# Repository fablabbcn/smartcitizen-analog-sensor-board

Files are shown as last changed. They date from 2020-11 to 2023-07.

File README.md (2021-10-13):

# SmartCitizen Analog Sensor Boards

This repository contains a set of boards that can interface the Smart Citizen Kit in different ways.

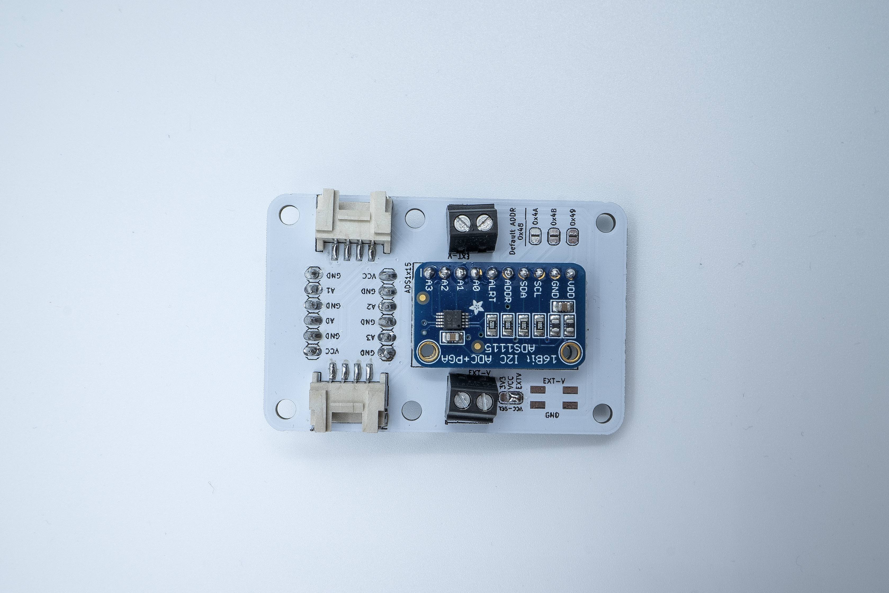
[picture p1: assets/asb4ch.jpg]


The SmartCitizen ASB is an expansion board for the [Smart Citizen Kit](https://github.com/fablabbcn/smartcitizen-kit-21) that provides connectivity to analog sensors with a high precission ADS1115 via I2C, with four configurable addresses. Daisy chainable up to 4 boards (or 2 in 8ch version) - with a total of 16 analog channels.

|Variant|# of Channels|External AREF needed|ADS format|
|:-:|:-:|:-:|:-:|
|4-channel|4|Y|SMD or [shield by adafruit](https://www.adafruit.com/product/1085)|
|8-channel-step|8|N|SMD|

## Characteristics

### Operating voltage

Natively operates at 3.3V, but can use also up to 5.5V in EXT-V, and with a selectable jumper. It integrates a level-shifter from the GROVE connector's voltage to EXT-V.

### Connectivity

I2C, from 3.3V up to 5.5V.

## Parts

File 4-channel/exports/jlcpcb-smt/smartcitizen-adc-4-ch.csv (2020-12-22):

Comment | Designator | Footprint | LCSC
10n | C1 | fab:fab-C1206FAB | C1944
100n | C2 | fab:fab-C1206FAB | C24497
1uF | C3,C4 | fab:fab-C1206FAB | C1848
1.5 kΩ | FB1,FB2 | fab:fab-R1206FAB | C21517
10k | R1,R2,R3,R4,R5,R6 | fab-R1206FAB | C17902
NMOSFET | T1,T2 | fab-SOT-23 | C431497
ADS1115IDGS | U1 | Package_SO:TSSOP-10_3x3mm_P0.5mm | C37593

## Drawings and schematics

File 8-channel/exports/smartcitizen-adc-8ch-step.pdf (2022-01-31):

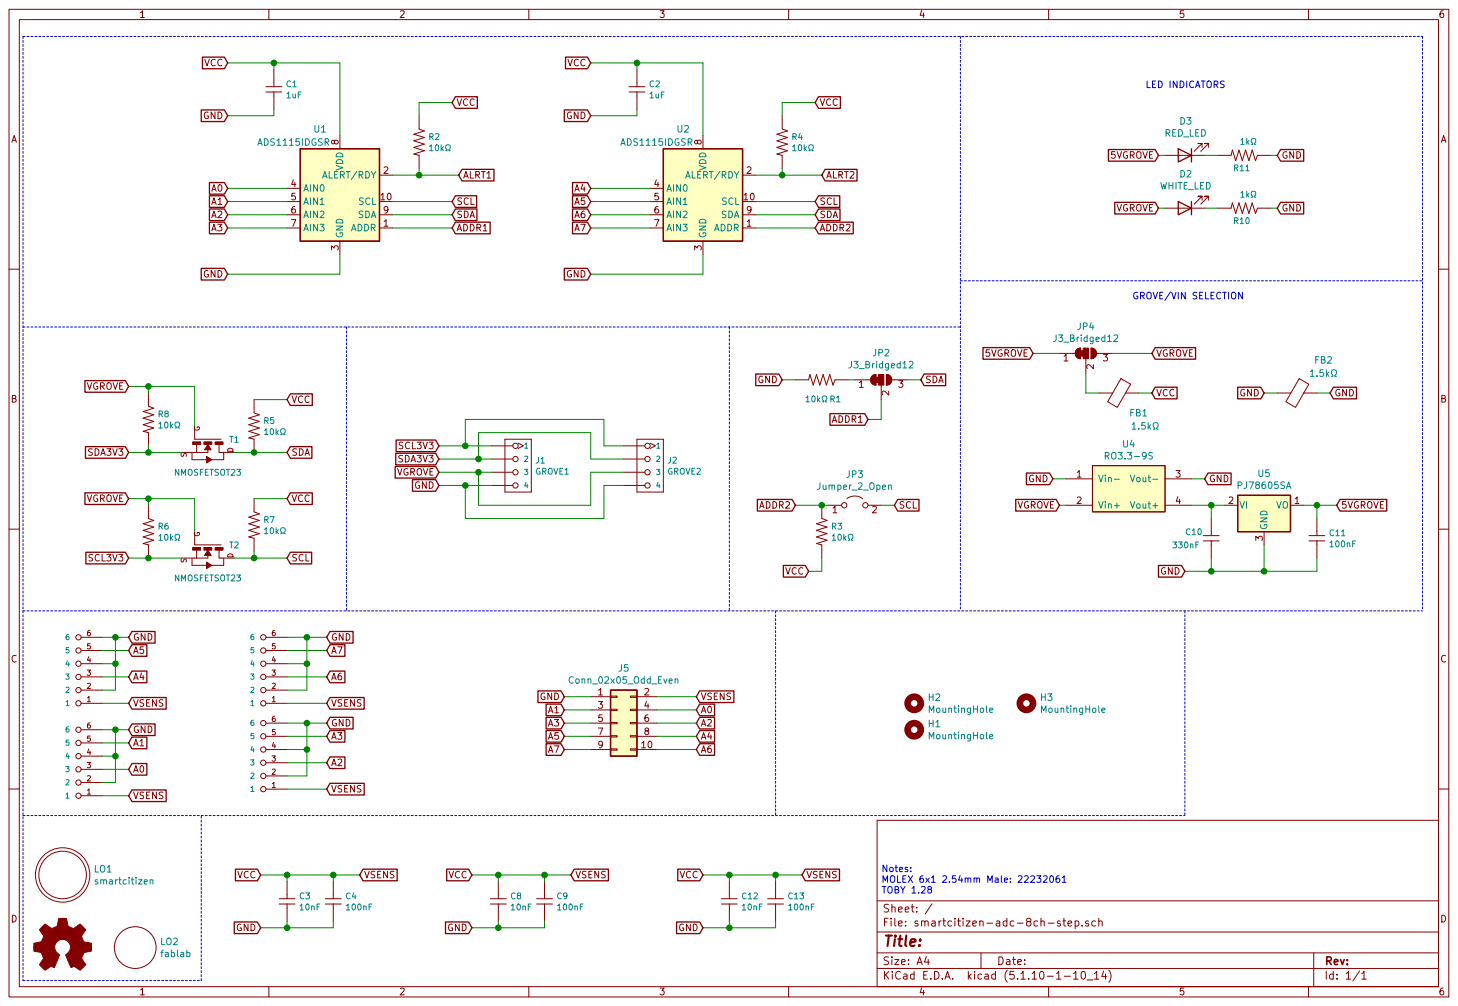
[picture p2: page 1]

Notes: MOLEX 6x1 2.54mm Male: 22232061 TOBY 1.28

File: smartcitizen-adc-8ch-step.sch Sheet: /
Id: 1/1 Title:

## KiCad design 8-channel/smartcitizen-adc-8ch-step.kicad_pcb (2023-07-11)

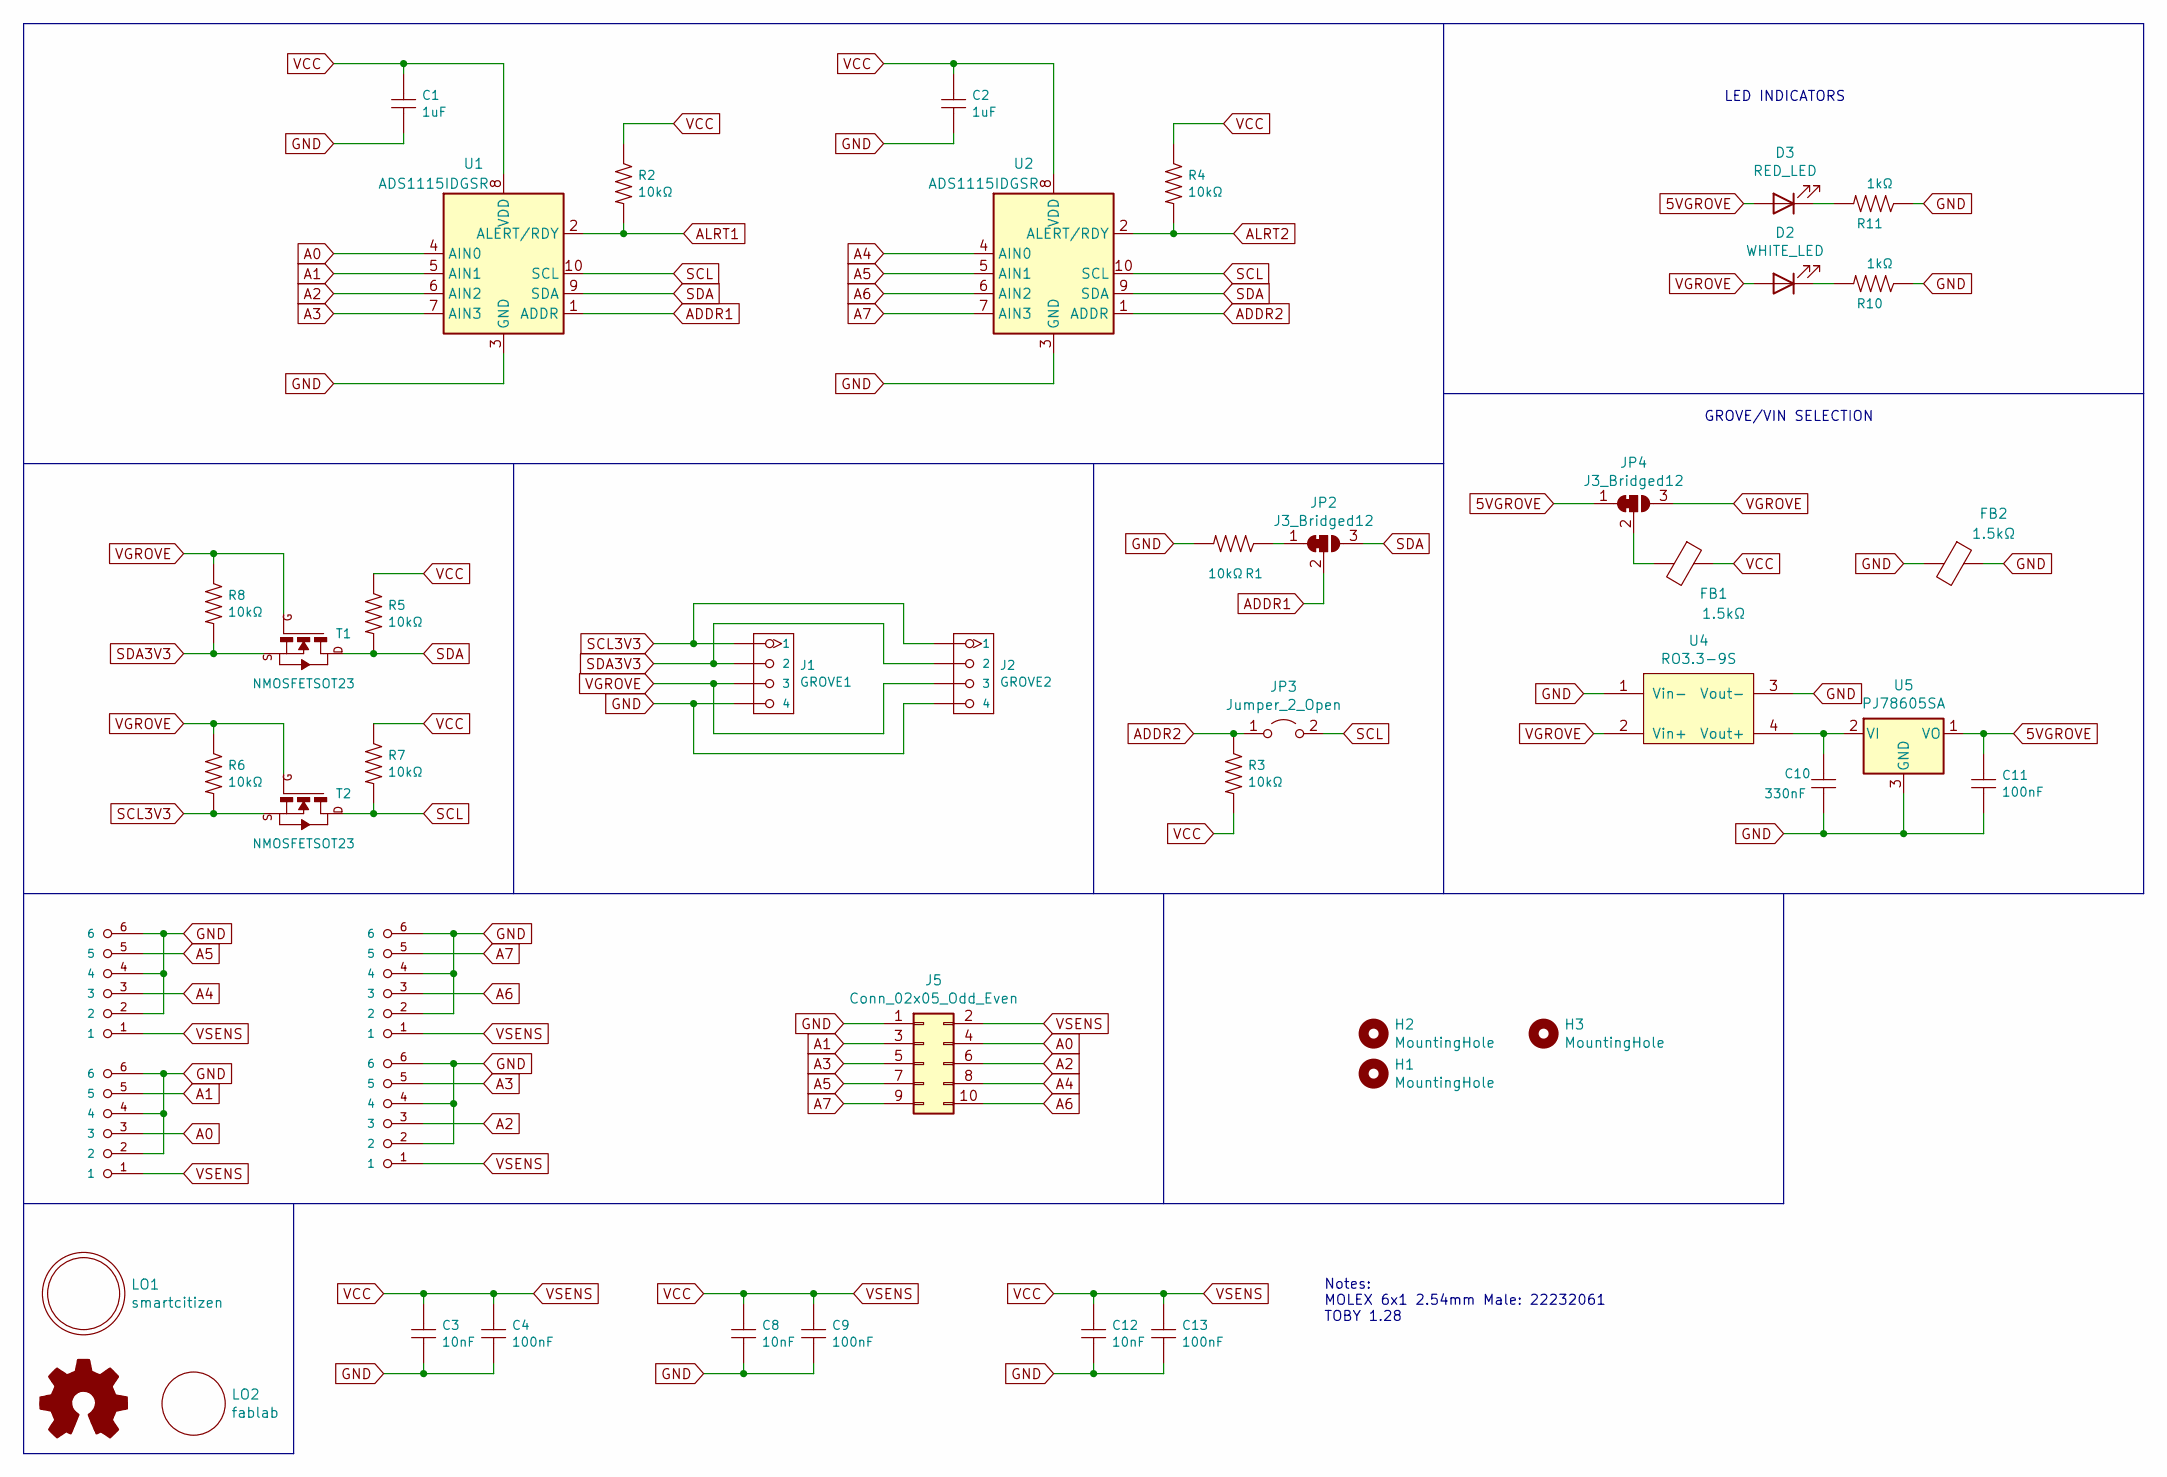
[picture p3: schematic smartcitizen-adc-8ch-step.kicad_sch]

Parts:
C1, C2: 1uF; C_0805_2012Metric; MFR.Part # CL21B105KBFNNNE; LCSC C28323
C3, C8, C12: 10nF; C_0805_2012Metric_Pad1.18x1.45mm_HandSolder; MFR.Part # CC0805KRX7R0BB103; LCSC C107135
C4, C9, C13: 100nF; C_0805_2012Metric_Pad1.18x1.45mm_HandSolder; MFR.Part # CC0805JRX7R9BB104; LCSC C111492
C10: 330nF; fab-C1206FAB; MFR.Part # CL31B334KBFNNNE; LCSC C307572
C11: 100nF; fab-C1206FAB; MFR.Part # CL31B104KBCNNNC; LCSC C24497
D2: WHITE_LED; LED_0402_1005Metric; MFR.Part # BL-HZ337A-L6-TRB; LCSC C189305
D3: RED_LED; LED_0402_1005Metric; MFR.Part # 2SA0402S11A0JT01; LCSC C233194
FB1, FB2: 1.5kΩ; R_0805_2012Metric_Pad1.20x1.40mm_HandSolder; MFR.Part # MMZ2012Y152B; LCSC C21517
H1, H2, H3: MountingHole; MountingHole_3.2mm_M3
J1: GROVE1; HW4-SMD-2.0-90D
J2: GROVE2; HW4-SMD-2.0-90D
J5: Conn_02x05_Odd_Even; PinSocket_2x05_P2.00mm_Vertical
JP2, JP4: J3_Bridged12; SolderJumper-3_P1.3mm_Bridged12_RoundedPad1.0x1.5mm
JP3: Jumper_2_Open; SolderJumper-2_P1.3mm_Open_RoundedPad1.0x1.5mm
LO1: smartcitizen
LO2: fablab
M1, M2, M3, M4: PINHD-1x06-HEADER; Molex_KK-254_AE-6410-06A_1x06_P2.54mm_Vertical
OSH1: Logo_Open_Hardware_Small; OSHW-Symbol_6.7x6mm_SilkScreen
R1, R2, R3, R4, R5, R6, R7, R8: 10kΩ; R_0603_1608Metric; MFR.Part # 0603WAF1002T5E; LCSC C25804
R10, R11: 1kΩ; R_0402_1005Metric; MFR.Part # 0402WGF1001TCE; LCSC C11702
T1, T2: NMOSFETSOT23; fab-SOT-23; MFR.Part # SI2310; LCSC C431497
U1, U2: ADS1115IDGSR; TSSOP-10_3x3mm_P0.5mm; MFR.Part # ADS1115IDGSR; LCSC C37593
U4: RO3.3-9S; Converter_DCDC_RECOM_RO_3.309S
U5: PJ78605SA; SOT-23; LCSC C411751

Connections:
5VGROVE: C11.1, D3.2 (A), JP4.1 (A), U5.1 (VO)
A0: J5.4, M2.3, U1.4 (AIN0)
A1: J5.3, M2.5, U1.5 (AIN1)
A2: J5.6, M4.3, U1.6 (AIN2)
A3: J5.5, M4.5, U1.7 (AIN3)
A4: J5.8, M1.3, U2.4 (AIN0)
A5: J5.7, M1.5, U2.5 (AIN1)
A6: J5.10, M3.3, U2.6 (AIN2)
A7: J5.9, M3.5, U2.7 (AIN3)
ADDR1: JP2.2 (C), U1.1 (ADDR)
ADDR2: JP3.1 (A), R3.1, U2.1 (ADDR)
ALRT1: R2.2, U1.2 (ALERT/RDY)
ALRT2: R4.2, U2.2 (ALERT/RDY)
GND: C1.2, C2.2, C3.2, C4.2, C8.2, C9.2, C10.2, C11.2, C12.2, C13.2, FB2.1, FB2.2, J1.4, J2.4, J5.1, M1.2, M1.4, M1.6, M2.2, M2.4, M2.6, M3.2, M3.4, M3.6, M4.2, M4.4, M4.6, R1.2, R10.1, R11.1, U1.3 (GND), U2.3 (GND), U4.1 (Vin-), U4.3 (Vout-), U5.3 (GND)
unnamed: C10.1, U4.4 (Vout+), U5.2 (VI)
unnamed: D2.1 (K), R10.2
unnamed: D3.1 (K), R11.2
unnamed: FB1.2, JP4.2 (C)
unnamed: JP2.1 (A), R1.1
SCL: JP3.2 (B), R7.2, T2.1 (D), U1.10 (SCL), U2.10 (SCL)
SCL3V3: J1.1, J2.1, R6.2, T2.2 (S)
SDA: JP2.3 (B), R5.2, T1.1 (D), U1.9 (SDA), U2.9 (SDA)
SDA3V3: J1.2, J2.2, R8.2, T1.2 (S)
VCC: C1.1, C2.1, C3.1, C4.1, C8.1, C9.1, C12.1, C13.1, FB1.1, J5.2, M1.1, M2.1, M3.1, M4.1, R2.1, R3.2, R4.1, R5.1, R7.1, U1.8 (VDD), U2.8 (VDD)
VGROVE: D2.2 (A), J1.3, J2.3, JP4.3 (B), R6.1, R8.1, T1.3 (G), T2.3 (G), U4.2 (Vin+)

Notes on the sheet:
LED INDICATORS
Notes: MOLEX 6x1 2.54mm Male: 22232061 TOBY 1.28
GROVE/VIN SELECTION

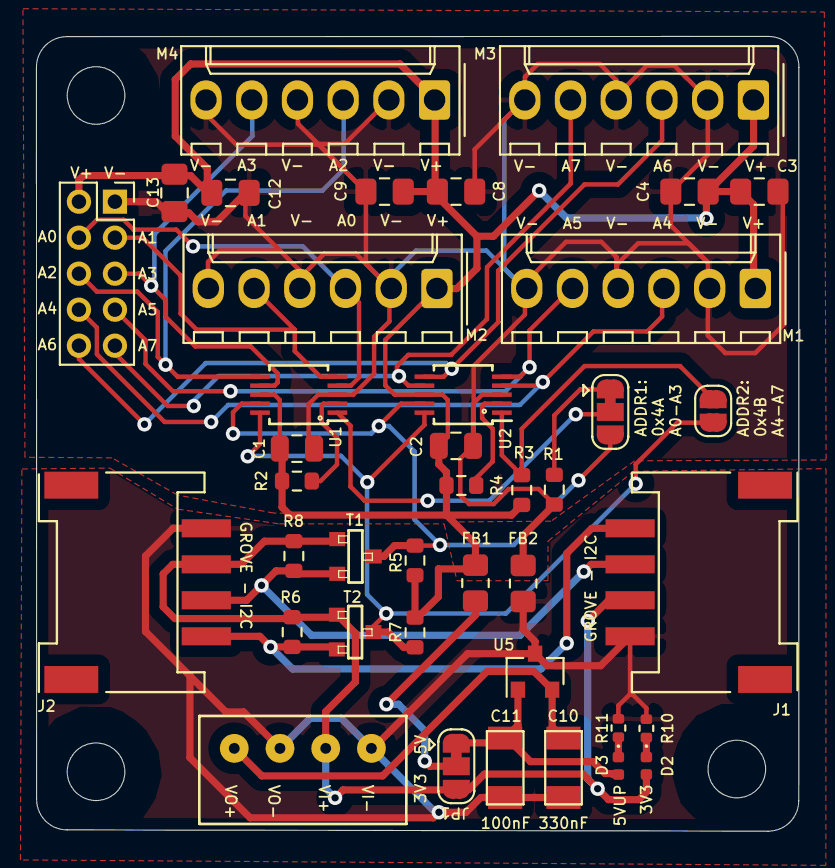
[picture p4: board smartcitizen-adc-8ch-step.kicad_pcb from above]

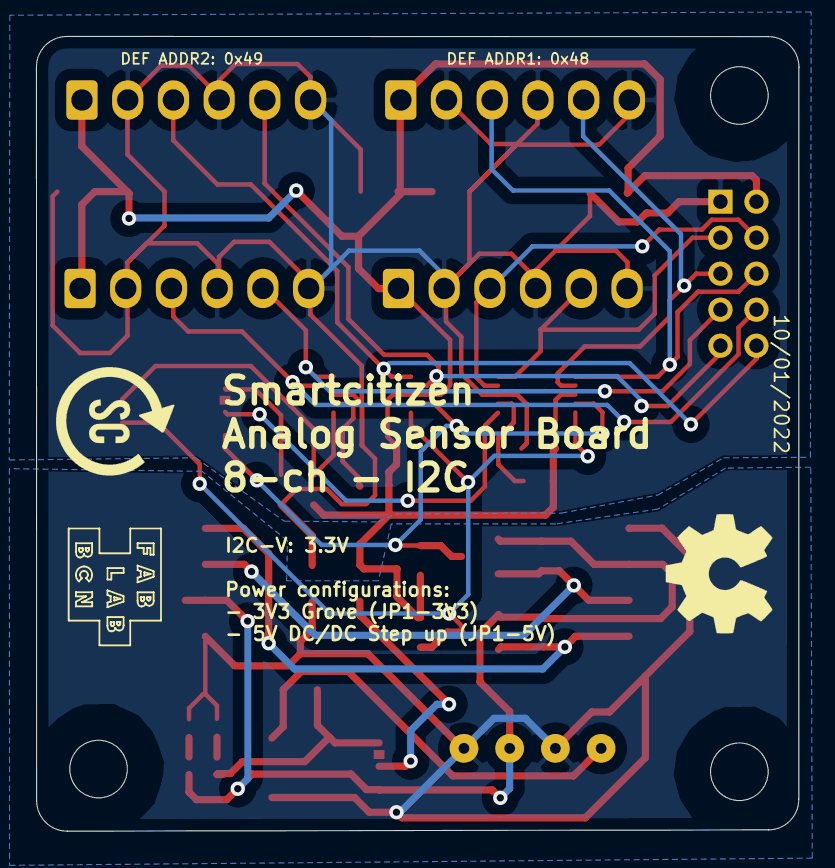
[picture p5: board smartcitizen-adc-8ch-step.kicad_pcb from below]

Board: 2 copper layers, 42.4 x 44.1 mm, 46 parts (3 on the bottom side), 25 nets.

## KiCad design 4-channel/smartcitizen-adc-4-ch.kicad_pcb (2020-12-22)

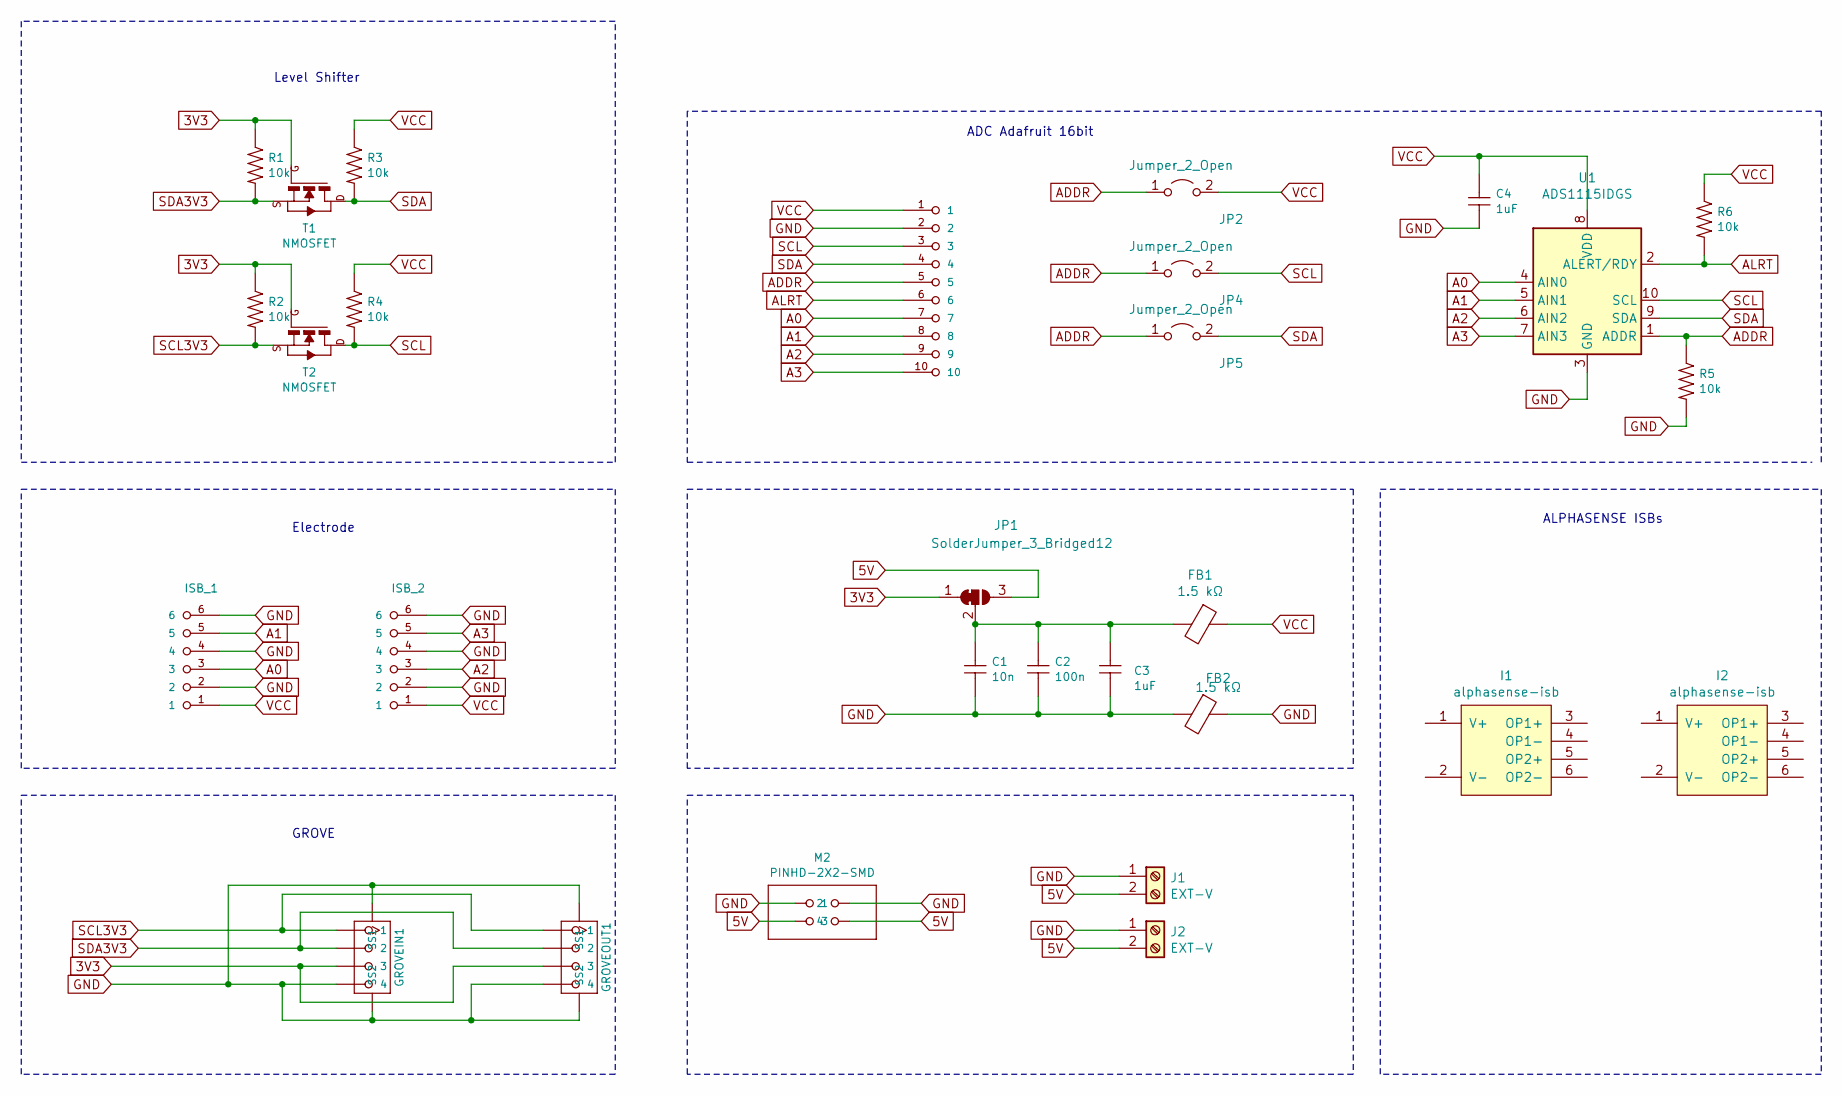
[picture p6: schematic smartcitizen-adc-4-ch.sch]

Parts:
C1: 10n; fab-C1206FAB; LCSC C1944
C2: 100n; fab-C1206FAB; LCSC C24497
C3, C4: 1uF; fab-C1206FAB; LCSC C1848
FB1, FB2: 1.5 kΩ; fab-R1206FAB; LCSC C21517
GROVEIN1: GROVE-CONNECTOR-SMD-90D_4+2P-2.0_; HW4-SMD-2.0-90D
GROVEOUT1: GROVE-CONNECTOR-DIP_4P-2.0_; HW4-SMD-2.0-90D
I1, I2: alphasense-isb
ISB_1, ISB_2: PINHD-1x06-HEADER; fab-1X06
J1, J2: EXT-V; TerminalBlock_Phoenix_PT-1,5-2-3.5-H_1x02_P3.50mm_Horizontal
JP1: SolderJumper_3_Bridged12; SolderJumper-3_P1.3mm_Bridged12_RoundedPad1.0x1.5mm_NumberL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
JP2, JP4, JP5: Jumper_2_Open; SolderJumper-2_P1.3mm_Open_RoundedPad1.0x1.5mm
M1: PINHD-1x10-HEADER; ads11x5
M2: PINHD-2X2-SMD; fab-2X02SMD
R1, R2, R3, R4, R5, R6: 10k; fab-R1206FAB; LCSC C17902
T1: NMOSFET; fab-SOT-23; LCSC C431497
T2: NMOSFET; fab-SOT-23; LCSC NCE2304
U1: ADS1115IDGS; TSSOP-10_3x3mm_P0.5mm; LCSC C37593

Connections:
3V3: GROVEIN1.3, GROVEOUT1.3, JP1.1 (A), R1.1, R2.1, T1.3 (G), T2.3 (G)
5V: J1.2, J2.2, JP1.3 (B), M2.3, M2.4
A0: ISB_1.3, M1.7, U1.4 (AIN0)
A1: ISB_1.5, M1.8, U1.5 (AIN1)
A2: ISB_2.3, M1.9, U1.6 (AIN2)
A3: ISB_2.5, M1.10, U1.7 (AIN3)
ADDR: JP2.1 (A), JP4.1 (A), JP5.1 (A), M1.5, R5.1, U1.1 (ADDR)
ALRT: M1.6, R6.2, U1.2 (ALERT/RDY)
GND: C1.2, C2.2, C3.2, C4.2, FB2.1, FB2.2, GROVEIN1.4, GROVEIN1.5 (SS1), GROVEIN1.6 (SS2), GROVEOUT1.4, GROVEOUT1.5 (SS1), GROVEOUT1.6 (SS2), ISB_1.2, ISB_1.4, ISB_1.6, ISB_2.2, ISB_2.4, ISB_2.6, J1.1, J2.1, M1.2, M2.1, M2.2, R5.2, U1.3 (GND)
unnamed: C1.1, C2.1, C3.1, FB1.2, JP1.2 (C)
SCL: JP4.2 (B), M1.3, R4.2, T2.1 (D), U1.10 (SCL)
SCL3V3: GROVEIN1.1, GROVEOUT1.1, R2.2, T2.2 (S)
SDA: JP5.2 (B), M1.4, R3.2, T1.1 (D), U1.9 (SDA)
SDA3V3: GROVEIN1.2, GROVEOUT1.2, R1.2, T1.2 (S)
VCC: C4.1, FB1.1, ISB_1.1, ISB_2.1, JP2.2 (B), M1.1, R3.1, R4.1, R6.1, U1.8 (VDD)

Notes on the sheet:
Level Shifter
ADC Adafruit 16bit
Electrode
GROVE
ALPHASENSE ISBs

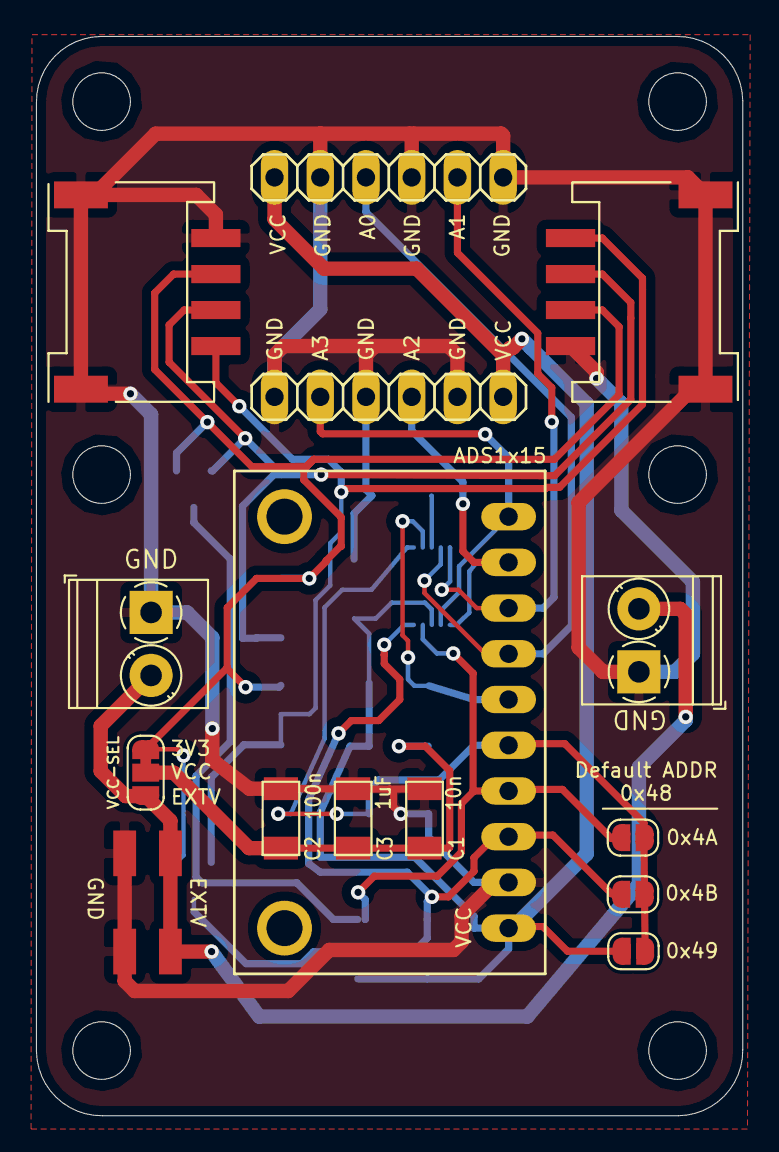
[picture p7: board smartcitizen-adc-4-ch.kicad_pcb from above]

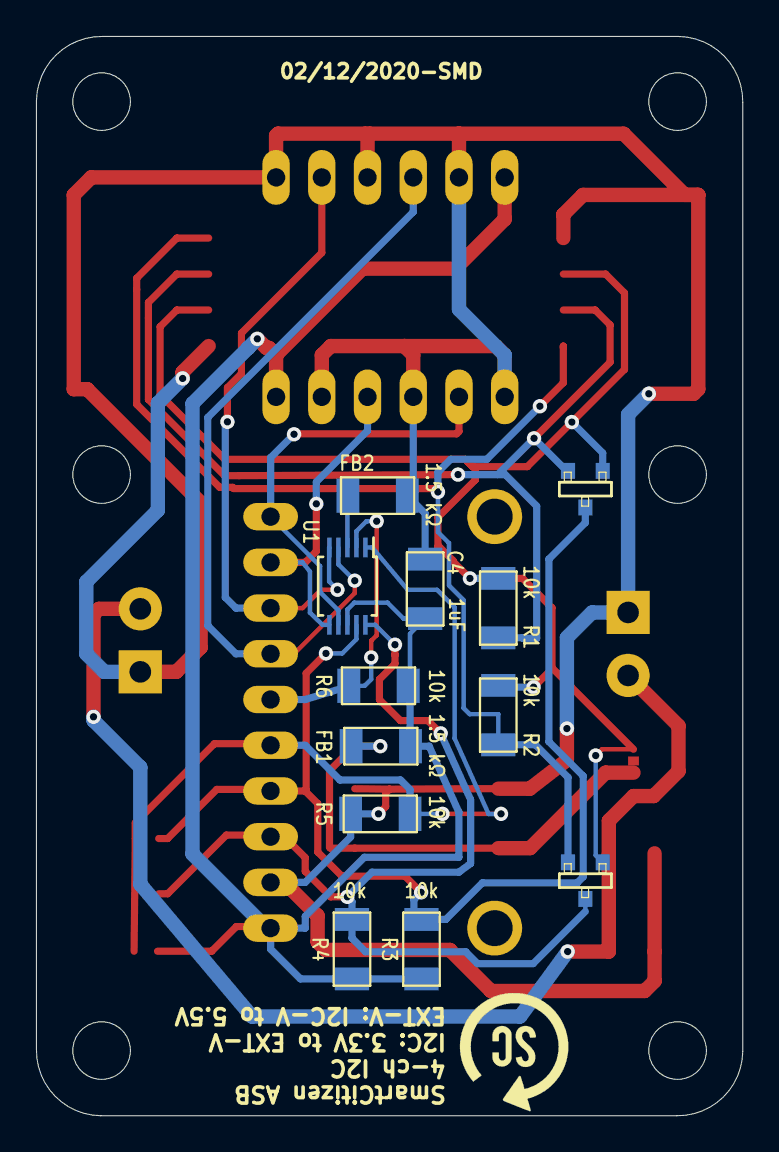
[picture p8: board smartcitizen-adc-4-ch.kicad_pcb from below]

Board: 2 copper layers, 39.2 x 60.0 mm, 27 parts (12 on the bottom side), 15 nets.

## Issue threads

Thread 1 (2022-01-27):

.SCH files will not open in Autodesk Eagle or Fusion 360

bryn51, 2022-01-27:
If I need to eyeball the schematic then I need a viewer that opens the files.  I am just guessing what to use; but most likely Eagle.

I find that there is no PDF version of the schematic available to view; and that the (.sch) files will not open in Autodesk Eagle (current version)  or Autodesk 360 (current version).

These issues are easily corrected; and should be.

oscgonfer, 2022-01-31:
The design files are done in Kicad 5, not supporting Autodesk stuff, sorry.

For the schematic, will add it now.

oscgonfer, 2022-01-31:
https://github.com/fablabbcn/smartcitizen-analog-sensor-board/blob/master/8-channel/exports/smartcitizen-adc-8ch-step.pdf

Closed 2022-01-31.

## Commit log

2020-06-30 4 channel ADC board
    [smartcitizen-adc-4-ch.csv, smartcitizen-adc-4-ch.kicad_pcb, smartcitizen-adc-4-ch.sch]
2020-07-01 Add 8 channel board
    [smartcitizen-adc-8ch.csv, smartcitizen-adc-8ch.kicad_pcb, smartcitizen-adc-8ch.sch]
2020-07-06 Add gerbers
    [smartcitizen-adc-4-ch-B_Cu.gbr, smartcitizen-adc-4-ch-B_Mask.gbr, smartcitizen-adc-4-ch-B_Paste.gbr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]
2020-07-07 4-channel exports
    [smartcitizen-adc-4-ch-B_Cu.gbr, smartcitizen-adc-4-ch-B_Mask.gbr, smartcitizen-adc-4-ch-B_Paste.gbr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]
2020-07-07 8-channel footprint
    [smartcitizen-adc-8ch.kicad_pcb]
2020-07-07 4-channel on pcb version
    [smartcitizen-adc-4-ch-B_Cu.gbr, smartcitizen-adc-4-ch-B_Mask.gbr, smartcitizen-adc-4-ch-B_Paste.gbr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]
2020-12-22 Move traces out of screw, move components to bottom layer for SMD
    [smartcitizen-adc-4-ch-B_Cu.gbr, smartcitizen-adc-4-ch-B_Mask.gbr, smartcitizen-adc-4-ch-B_Paste.gbr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]
2021-04-15 Add 8-ch USB version
    [smartcitizen-adc-8ch-ps.kicad_pcb, smartcitizen-adc-8ch-ps.sch]
2021-05-29 Add 8-channel version
    [smartcitizen-adc-8ch-step.kicad_pcb, smartcitizen-adc-8ch-step.sch]
2021-06-13 Add reduced 8-channel step-up version
    [smartcitizen-adc-8ch-step.kicad_pcb, smartcitizen-adc-8ch-step.sch]
2021-07-10 Stable version fixing address issue
    [smartcitizen-adc-8ch-step.kicad_pcb, smartcitizen-adc-8ch-step.sch]
2021-10-13 Update to new 8-channel board
    [smartcitizen-adc-8ch-B_Cu.gbr, smartcitizen-adc-8ch-B_Mask.gbr, smartcitizen-adc-8ch-B_Paste.gbr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]
2022-01-31 8-channel board changes and schematic
    [smartcitizen-adc-8ch-step.kicad_pcb, smartcitizen-adc-8ch-step.sch]
2023-07-11 Fix missing symbols
    [smartcitizen-adc-8ch-step.kicad_pcb, smartcitizen-adc-8ch-step.kicad_sch]
